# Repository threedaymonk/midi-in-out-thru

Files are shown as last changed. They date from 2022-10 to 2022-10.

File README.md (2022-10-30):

# MIDI In/Out/Thru

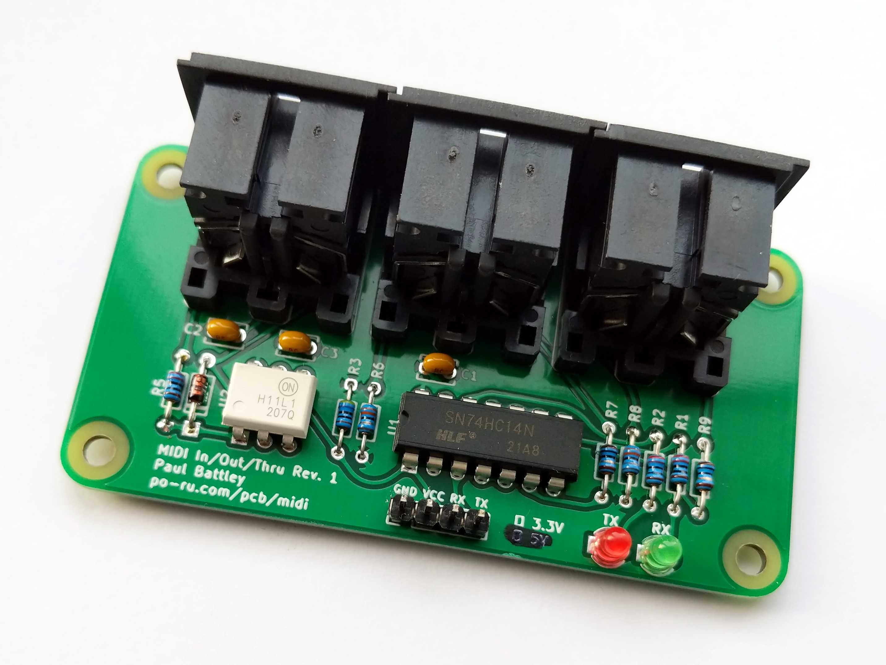
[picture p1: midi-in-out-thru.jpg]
Assembled board


I wanted a MIDI interface for microcontrollers that would

- work on 3.3V,
- use full-size DIN connectors,
- include MIDI Thru, and
- have all the connectors in one line.

This achieves that. You can attach it to a Raspberry Pi to give MIDI in to
[MiniDexed](https://github.com/probonopd/MiniDexed) or to a Raspberry Pi Pico
to make a USB to MIDI interface with [MIDI adapter
code](https://github.com/rsta2/pico/tree/main/midi_adapter).

If you don't want activity LEDs, you can omit R1, R2, LED1, LED2.

It's also possible to adapt this to 5V by changing R1 and R2 to 330 ohms,
and R6, R7, R8 and R9 to 220 ohms.

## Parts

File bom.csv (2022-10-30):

Ref | Quantity | Value | Details
C1, C2, C3 | 3 | 100n | 2.5mm pitch
D1 | 1 | 1N914
J1 | 1 | 1x4 pin header
J2, J3, J4 | 3 | DIN5 180° socket | RS 491-087 or Multicomp PSG03463 or Deltron 671-0501
LED1 | 1 | Green
LED2 | 1 | Red
R1, R2 | 2 | 180 | (or 220)
R3 | 1 | 470
R5 | 1 | 220
R6, R8 | 2 | 33
R7, R9 | 2 | 10
U1 | 1 | 74HC14
U2 | 1 | H11L1

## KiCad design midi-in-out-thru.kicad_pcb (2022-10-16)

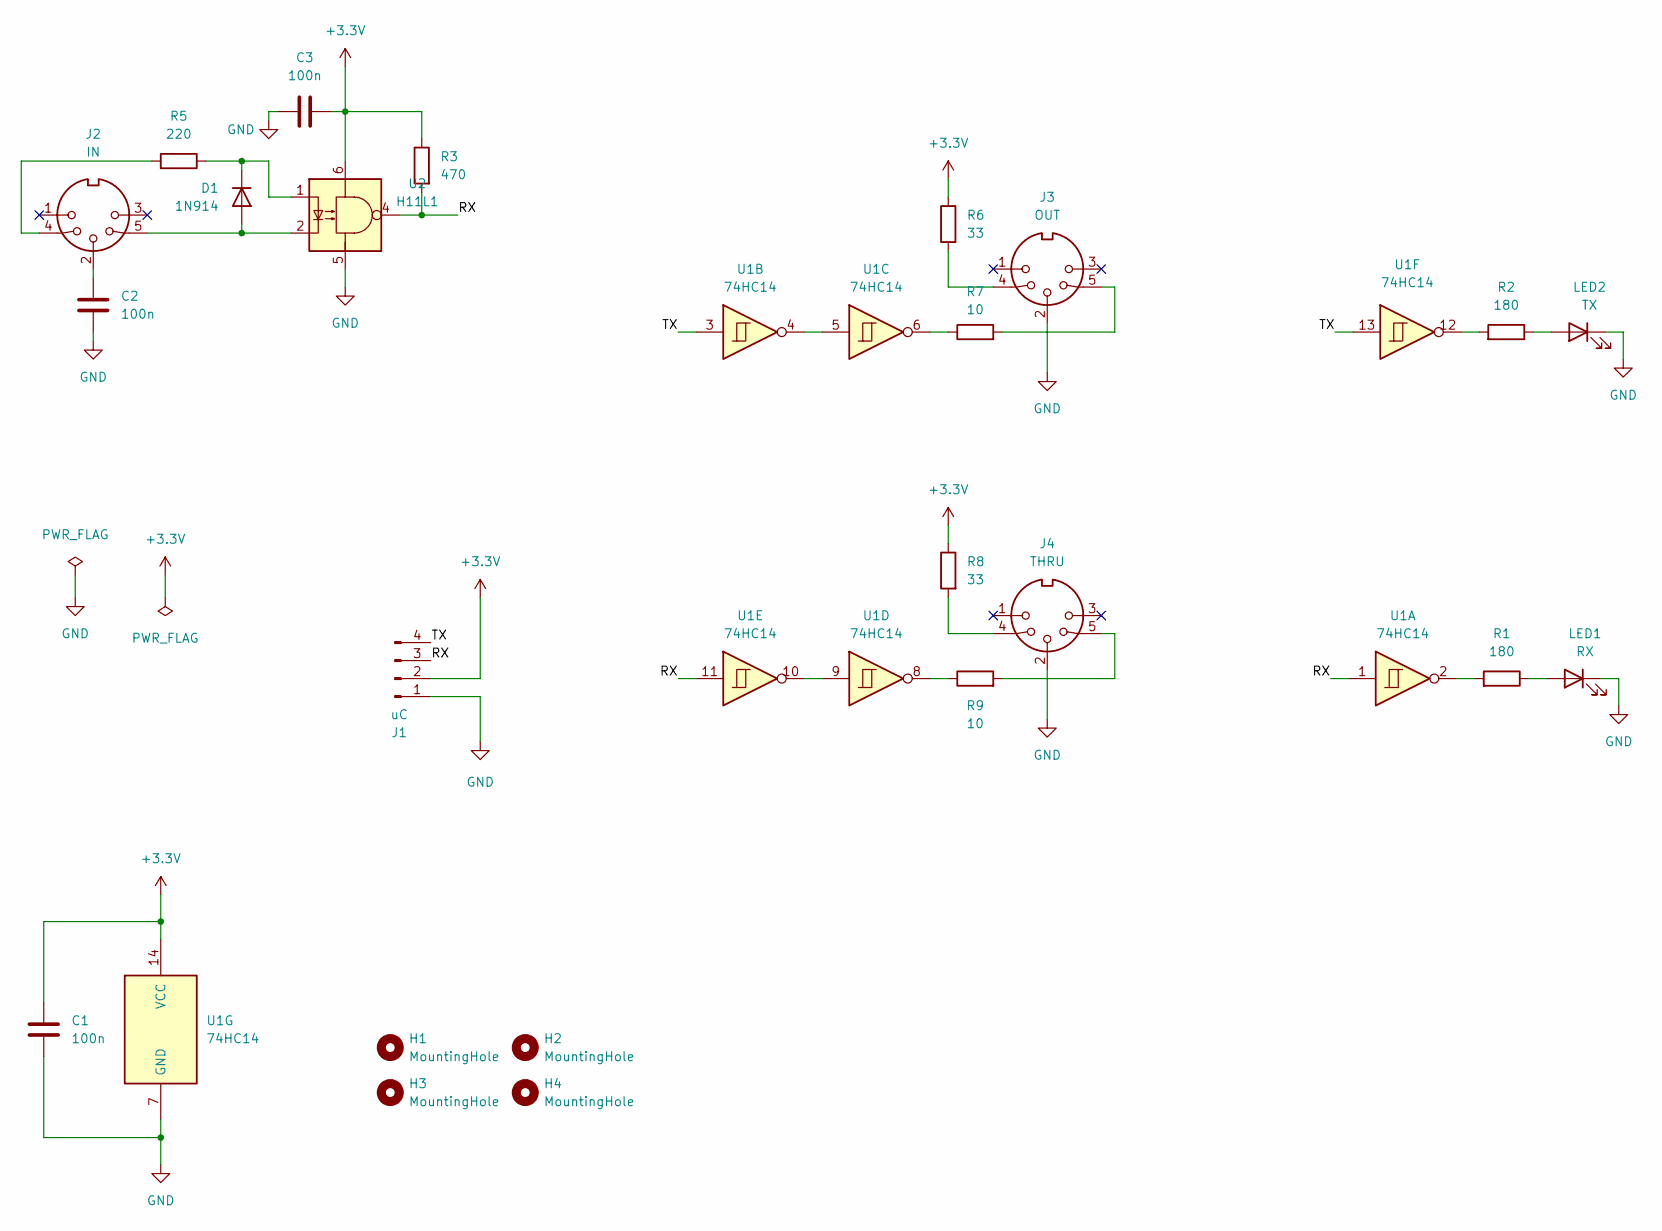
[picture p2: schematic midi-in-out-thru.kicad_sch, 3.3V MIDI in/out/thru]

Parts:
C1, C2, C3: 100n; C_Disc_D3.8mm_W2.6mm_P2.50mm
D1: 1N914; D_DO-35_SOD27_P7.62mm_Horizontal
H1, H2, H3, H4: MountingHole; MountingHole_3.2mm_M3
J1: uC; PinHeader_1x04_P2.54mm_Vertical
J2: IN; MIDI_DIN5
J3: OUT; MIDI_DIN5
J4: THRU; MIDI_DIN5
LED1: RX; LED_D3.0mm
LED2: TX; LED_D3.0mm
R1, R2: 180; R_Axial_DIN0204_L3.6mm_D1.6mm_P7.62mm_Horizontal
R3: 470; R_Axial_DIN0204_L3.6mm_D1.6mm_P7.62mm_Horizontal
R5: 220; R_Axial_DIN0204_L3.6mm_D1.6mm_P7.62mm_Horizontal
R6, R8: 33; R_Axial_DIN0204_L3.6mm_D1.6mm_P7.62mm_Horizontal
R7, R9: 10; R_Axial_DIN0204_L3.6mm_D1.6mm_P7.62mm_Horizontal
U1: 74HC14; DIP-14_W7.62mm
U2: H11L1; DIP-6_W7.62mm

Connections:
+3.3V: C1.1, C3.2, J1.2, R3.1, R6.1, R8.1, U1.14 (VCC), U2.6
/RX: J1.3, R3.2, U1.1, U1.11, U2.4
/TX: J1.4, U1.3, U1.13
GND: C1.2, C2.2, C3.1, J1.1, J3.2, J4.2, LED1.1 (K), LED2.1 (K), U1.7 (GND), U2.5
unnamed: C2.1, J2.2
unnamed: D1.1 (K), R5.1, U2.1
unnamed: D1.2 (A), J2.5, U2.2
unnamed: J2.4, R5.2
unnamed: J3.4, R6.2
unnamed: J3.5, R7.2
unnamed: J4.4, R8.2
unnamed: J4.5, R9.2
unnamed: LED1.2 (A), R1.1
unnamed: LED2.2 (A), R2.1
unnamed: R1.2, U1.2
unnamed: R2.2, U1.12
unnamed: R7.1, U1.6
unnamed: R9.1, U1.8
unnamed: U1.4, U1.5
unnamed: U1.9, U1.10

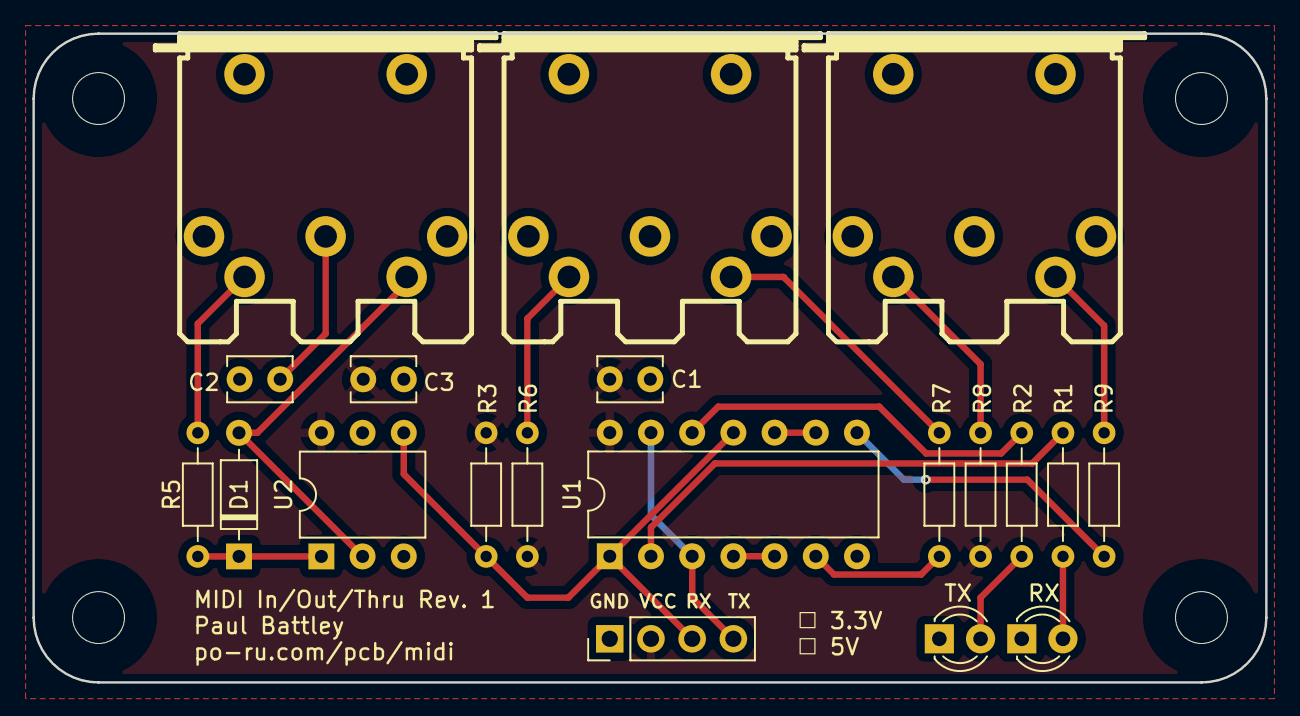
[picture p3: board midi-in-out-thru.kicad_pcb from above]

Board: 2 copper layers, 76.0 x 40.0 mm, 24 parts (0 on the bottom side), 20 nets.

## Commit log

2022-10-02 Copy 6n138 circuit
    [midi-in-out-thru.kicad_pcb, midi-in-out-thru.kicad_sch]
2022-10-02 Use H11L1
    Resistor values taken from CA-033 Update 2014
    [midi-in-out-thru.kicad_sch]
2022-10-02 First PCB layout
    [midi-in-out-thru.kicad_pcb]
2022-10-03 Completed initial layout
    [midi-in-out-thru.kicad_pcb, midi-in-out-thru.kicad_sch]
2022-10-16 Smaller resistors, neater layout
    [midi-in-out-thru.kicad_pcb, midi-in-out-thru.kicad_sch]
2022-10-16 Tweak tracks before rounding
    [midi-in-out-thru.kicad_pcb]
2022-10-16 Remove extra layers
    [midi-in-out-thru.kicad_pcb]
2022-10-30 Add BOM
    [bom.csv]
